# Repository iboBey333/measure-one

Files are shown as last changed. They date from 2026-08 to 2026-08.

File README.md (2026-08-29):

# **measure-one**
### A Caliper? A PCB? NO! IT IS A PCB CALIPER!

Measure-One is a caliper that is made entirely from PCBs. 

Measure-One can measure in both centimeters and inches. And it can measure anything up to 30 cm (~ 11.8 inches).

A render of measure-one in blender:

Measure-One_Final

___

## The Reason and the Inspiration for This Project

I first had the idea to make this project when I saw JBlitzar's (btz) project "measure-zero". He made an pcb ruler and I asked to myself that if a ruler that is made from PCB looks that cool how would I caliper look? Also at the time that I started this project I was looking to get an caliper so it lined up perfectly :] At the end I ended up with a project like this. Altough the process had some problems I had fun making this project.

I also got the inspiration for measure-one's render from JBlitzar. I want to thank him A LOT. If you liked this project you might like his project too. You can check out his project from this link: https://github.com/JBlitzar/measure-zero
___

I made 2 version of the caliper PCB's. One with instructions and one without. I added these instructions cause some people may have problems putting together this caliper which has a total of 23 different piece designs. You can find how the instructions work in the next part.
___

## How to Understand the Instructions

I already stated how to use the instructions in one of my devlogs. Here is that part of that devlog:

Instructions have 3 different symbol types;

1. Letters inside a rectangle

   This symbol type consists of three symbols, `M_B`, `S`, and `S_P`. These symbols indicates which piece set the PCB is from. Each corresponds to a piece set:

   1. `M_B` → Main Body
   2. `S` → Slider
   3. `S_P` → Slider Pointer

2. Letters inside a circle

   This symbol type is used to indicate which piece of the set each PCB belongs to. For example if the symbol is a A inside a cirle, the PCB is the piece A in it's set, if it is a B inside a circle it is the piece B and so on... Also these symbols are generally right beeside the type 1 symbols that indicate the set. This makes it easier to know which sets which part the PCB is.

3. Only letters

   This symbols type is the most used one. They indicate which part will be connected to the nearest side or the nearest slot. These symbols only show the letter of the piece that is gonna be connected not the group. But keep in mind that the indicated piece is in the same group as the PCB. As I said it usually shows what is gonna be connected to the **nearest** part, but sometimes there isn't enough available space so they get squeezed to the same collumn and it is impossible to know which side it is for. I solved this by using small arrows to indicate the side they are for. 

I want to mention that all of these symbols are on the **silkscreen** layer of the PCB.
I also added "_W_I" at the end of these PCB files to indicate that it is with instructions

These are the photos of all of the silkscreen symbols/sketches: 

Type 1 (In a rectangle):



Type 2 (In a circle):



Type 3 (Only letters):



Also arrows are like this:



___

## Getting It for Yourself / Manufacturing

There is a total of 23 different pieces designs but when taking the 2 version (with instructions and without instructions) there are 46 different PCBs. All of the gerber files of these PCBs can be found in `Manufacturing` folder. The ones with instructions have `"_W_I"` at the end of their name. 

There are also the panelized PCB's gerbers. I made these gerbers my stitching up the other ones in the same group. But they have different number of designs in each panel. This part becomes very important when ordering it from a manufacturer. There are the different design counts of the panelized versions:

* Measure_One_Main_Body_Panelized / Measure_One_Main_Body_Panelized_W_I    **=**    **7**

* Measure_Slider_Body_Panelized / Measure_Slider_Body_Panelized_W_I    **=**   **8**

* Measure_Slider_Pointer_Body_Panelized / Measure_Slider_Pointer_Body_Panelized_W_I    **=**   **8**
___
You can also find the KiCad design files for these PCBs in the `Kicad` folder.
___

## Same Photos Of this Project







___
### BOM (Bill of Materials)
When I looked get these PCBs from JLCPCB it was nearly $120 + shipping. And that is probably what you are going to get when you try to order one yourself. But because I am in Türkiye and the taxes are quite strict I will get it from my local resellers and It will cost a lot more than the JLCPCBs international amount.

*Yet To Be Updated*

___
## License

This project is licensed under the **CC BY-NC-SA 4.0 License**. 

You may modify and redistribute this project under the terms of the **CC BY-NC-SA 4.0**, visit https://creativecommons.org/licenses/by-nc-sa/4.0/legalcode.txt for the license.

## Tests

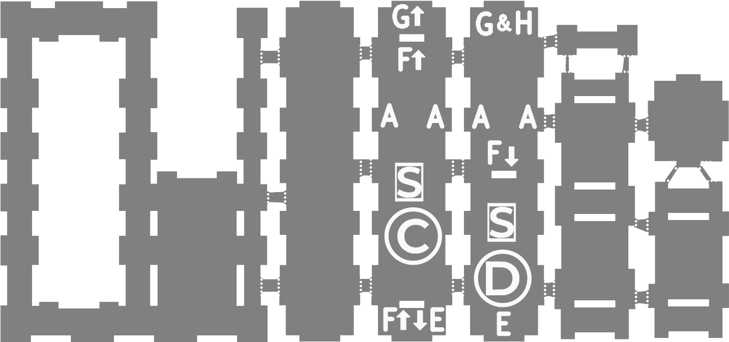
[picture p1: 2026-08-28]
Kicad/W_Instructions/Measure_One_Slider_W_I/Measure_One_Slider_Panelized_W_I/Untitled_Combined_Top.png

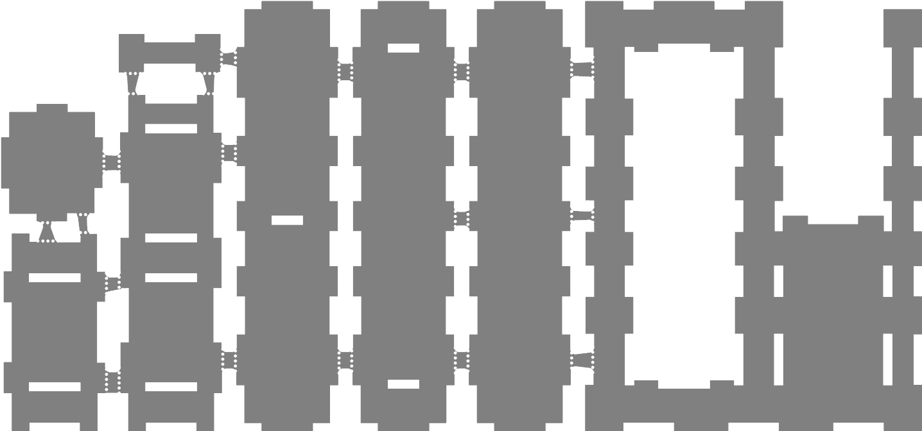
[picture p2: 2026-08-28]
Kicad/Measure_One_Slider/Measure_One_Slider_Panelized/Untitled_Combined_Bottom.png

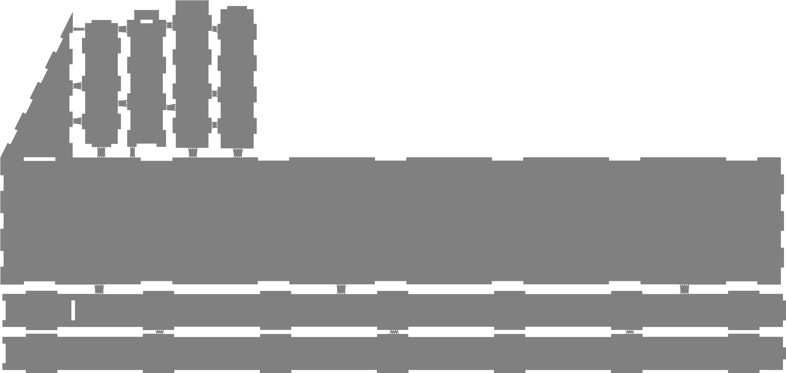
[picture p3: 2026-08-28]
Kicad/Measure_One_Main_Body/Measure_One_Main_Body_Panelized/Measure_One_Main_Body_Panelized_Combined_Bottom.png

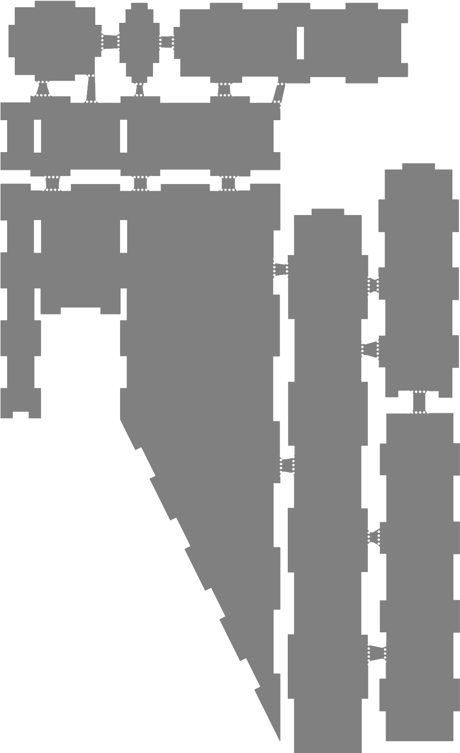
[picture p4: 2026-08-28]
Kicad/Measure_One_Slider_Pointer/Measure_One_Slider_Pointer_Panelized/Measure_One_Slider_Pointer_Panelized_Combined_Top.png

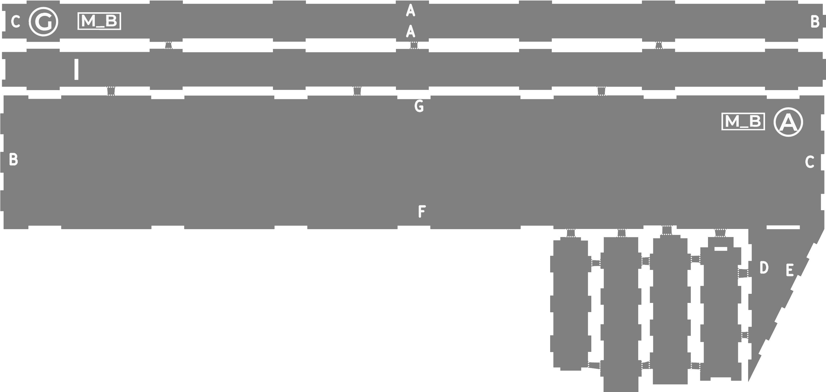
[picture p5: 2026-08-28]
Kicad/W_Instructions/Measure_One_Main_Body_W_I/Measure_One_Main_Body_Panelized_W_I/Measure_One_Main_Body_Panelized_W_I_Combined_Bottom.png

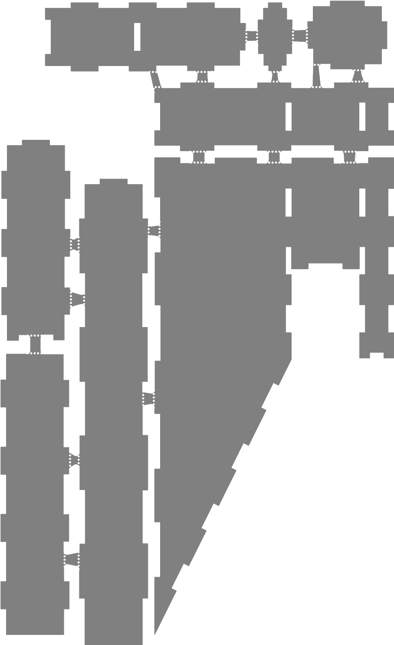
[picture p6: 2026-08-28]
Kicad/Measure_One_Slider_Pointer/Measure_One_Slider_Pointer_Panelized/Measure_One_Slider_Pointer_Panelized_Combined_Bottom.png

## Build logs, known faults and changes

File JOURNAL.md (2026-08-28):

# 3 August 2026 
I researched about how to make an custom caliper, PCB manufaturing and how to make this project durable so that it can actually be a useable piece.

After my researched I learned a few things: 

To make an caliper you need a few pieces;

▪  A main body,

▪  A slider,

▪  And a pointer thingy that is going to be attached to the slider. (This is actually a custom piece that is not necessary. But I find it to look better like this.) 

I also found out that PCBs are not really things that are very durable. This creates a *big* problem. The problem is when they aren't very durable they can just snap at the root and make it unusable. I plan to solve this problem by making the 2 main body and 2 slider parts that can fit together to make double the durability. I am not really sure if this will work but I think it's my only choice. 
___
I also did some sketches. I will later design the PCBs according to these sketches.



As I said there is 3 main parts of the caliper.
___
Also I am looking into integrating some useful parts like templates for circles, arcs and angles.
___
Also **thanks a lot** to JBlitzar (btz)'s project measure-zero to give me the idea for this project. I also talked to him and he said I can use the naming scheme. I also wanter to make a reference to his project because they are very alike. I will give the link to his projects github and forge page so you can look to it too!

https://github.com/JBlitzar/measure-zero

https://forge.hackclub.com/projects/972
___
Time Spent: 1 Hour

I was able to lapse 30 minutes of sketching but I couldn't lapsed the 30 minutes of research process.

___
# 5 August - 6 August 2026 
I made a CAD design in Autodesk Fusion. I luckily modeled it, cause I found out that my original design is so fragile to be usable. 

I made a new plan and design to solve this issue.
My new design again consists of 3 main parts. But they are not 1 piece per part as the previous one.
Now each part uses a few different pieces. These pieces will fit together to make an 3D object just like a 3D puzzle. This design will be way more durable and way more usable.





I didn't yet designed the puzzle joints. But I plan onworking on the joints this week.
___
I also want to modify the main body so it can be used as a container for templates and rulers.
___
Time Spent: 2 Hours
___
# 8 August - 10 August 2026
I designed the puzzle piece sets in CAD. I will use these designs to visualize my project and to plan the outlines of the PCBs. I gave the holes 0.2 mm of clearance to be more reliable.

These are some photos of the designs:






There are a total of 22 **unique** pieces. But the total piece count is 32 pieces.
I know that this is a lot of different PCBs. But I couldn't figure out any other way to make it sturdier than the original 3 piece plan. 
___
Time Spent: 4 Hours 45 Minutes
___
# 17 August - 19 August 2026
I was gone for a few days.

Last 2 days I worked on getting the required shapes of the PCBs from my CAD design to KiCad. I used something called DXF files that I just learned few days ago. Apparently they are very useful when you need to do something like this :) 

After this one done. I only have a few things left to do to finish this project. The silkscreen and the build.





___

Time Spent: 1 Hour
___
# 19 August - 22 August 2026
I sketched the "measuring lines" for the main function of the project, I don't know what they are called but I will refer them like this. My plan was normally only 30 cm but I added the lines for measuring in inches to make it universal. I also used the Minecraft font for the numbers, because it is one of my favourites.

I also thought that the puzzle might be a bit hard for some because of that I did 2 different sets of pieces. They are exactly same dimensions **but** one is 
with instructions, I will meniotn how it will work later this devlog, and the other one is without any instruction.

Instructions have 3 different symbol types;

1. Letters inside a rectangle

   This symbol type consists of three symbols, `M_B`, `S`, and `S_P`. These symbols indicates which piece set the PCB is from. Each corresponds to a piece set:

   1. `M_B` → Main Body
   2. `S` → Slider
   3. `S_P` → Slider Pointer

2. Letters inside a circle

   This symbol type is used to indicate which piece of the set each PCB belongs to. For example if the symbol is a A inside a cirle, the PCB is the piece A in it's set, if it is a B inside a circle it is the piece B and so on... Also these symbols are generally right beeside the type 1 symbols that indicate the set. This makes it easier to know which sets which part the PCB is.

3. Only letters

   This symbols type is the most used one. They indicate which part will be connected to the nearest side or the nearest slot. These symbols only show the letter of the piece that is gonna be connected not the group. But keep in mind that the indicated piece is in the same group as the PCB. As I said it usually shows what is gonna be connected to the **nearest** part, but sometimes there isn't enough available space so they get squeezed to the same collumn and it is impossible to know which side it is for. I solved this by using small arrows to indicate the side they are for. 

I want to mention that all of these symbols are on the **silkscreen** layer of the PCB.
I also added "_W_I" at the end of these PCB files to indicate that it is with instructions

These are the photos of all of the silkscreen symbols/sketches: 

Type 1 (In a rectangle):



Type 2 (In a circle):



Type 3 (Only letters):



Also arrows are like this:



And finally the measuring lines:



___
After this done I only have 3 things left to do. 3D render for the forge page, uploading the gerber files to the github repo and writing a readme file.
I think I can do these in less than 1 week.
___
Time Spent: 4 Hours 20 Minutes
___
# 23 August - 24 August 2026
 **Cover image everybooodyyy!**
I designed the cover image in blender. After a bit of material prep, light work and post processing (compositing) it was done.
These took me more than 1 hour, like 2 hours but I only lapsed 1 hour and 10 minutes of it so that is my time spent.

These are some photos of my setup:





And these are some of the material and compositing photos:







I wanted to make this render look like an minimalist ad with studio lightning. I think I achieved that as much as possible with my level of experience (Beginner).
Also I waited 1+ hours for rendering time in the Cycles render engine. I did a few round of rendering and tuned it a bit each time. And this is the final render which is going to be my cover image:

Measure-One_Final

___
This project is nearly done. Only remaining thing to do is editing the github repo. And I am looking to finish that in the next 2 days. 
___
Time Spent: 1 Hour 10 Minutes
___
# August 26 - August 27 2026
I made a panelized pcb for every piece category. (Main_Body, Slider, Slider_Pointer, Main_Body_W_I, Slider_W_I, Slider_Pointer_W_I)
And I extracted all of the gerber files from (23+3)*2 = ***52*** different PCB designs.

These took a ***TON*** of time. I redid the panels nearly 2 times each and tested the gerber files if they work.

I am going to add these files to github next day with the other things that I have to do in my repo.

A photo of one of the panelized PCBs:


___
Time Spent: 2 Hours 43 Minutes
___
# August 28 2026
Apparently some of my gerbers was not quite working. The edge cuts were malformed. I tried fixing them by changing the DXF file type -that I used in previous days- to DXF R12 ASCII. That didn't worked :/ After trying that for over half an hour I just redrew the edge cuts that were malformed. And that worked :] 

I also tested all of them if it worked or not in JLCPCB. They turned out great!
___
Finally, I pushed these manufacturing (gerbers) and KiCad PCB files (.kicad_pro, .kicad_pcb etc.)




___
The only things left to do is, the BOM and the README file.
I plan to do them in next 2 days.
___
Time Spent: 1 Hours 15 Minutes
___

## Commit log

2026-08-10 Journal Entry 3
    Documented the 3D puzzle designing in CAD.
2026-08-28 Kicad And Manufacturing Upload Test
    [Measure_One_Main_Body_A.kicad_pcb, Measure_One_Main_Body_A.kicad_sch, Measure_One_Slider_Pointer_A.kicad_pcb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]
2026-08-28 KiCad PCBs and Gerber Upload
    Uploaded kicad pro and gerber files
    [Measure_One_Main_Body_A.kicad_pcb, Measure_One_Main_Body_A.kicad_sch, Measure_One_Main_Body_B.kicad_pcb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]
2026-08-29 Added Readme
    Added Readme. Is still doesn't contains the BOM.
